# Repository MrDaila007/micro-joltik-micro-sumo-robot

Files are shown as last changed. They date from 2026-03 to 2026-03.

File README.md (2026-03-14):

# Micro Joltik — Micro Sumo Robot

Micro Joltik is an autonomous micro sumo robot that detects opponents using IR proximity sensors and pushes them out of the arena. It features edge detection to stay within the ring boundary and RC5 remote control for start/stop.

## Hardware

- **MCU:** RP2040-zero
- **Motor driver:** TB6612FNG H-bridge driver
- **Motors:** 2× micro gear motors (tank drive)
- **Opponent detection:** 3× Pololu 38kHz IR proximity sensors (front left, center, right)
- **Edge detection:** 1× analog IR line sensor
- **Feedback:** 1× NeoPixel RGB LED
- **Control:** RC5 IR remote receiver
- **Chassis:** Plastic base with SolidWorks-designed 3D-printed parts

## Repository Structure

```
FIRMWARE/
  MicroJoltik_test_Firmware/   # Original test firmware
  MicroJoltik_stable/          # Stable firmware with bug fixes
CAD/                           # SolidWorks mechanical design files
doc/                           # Documentation (changelog, pinout)
```

## Building & Flashing

**Requirements:**
- Arduino IDE (or PlatformIO / VS Code with Arduino extension)
- Libraries: `Adafruit_NeoPixel`, `RC5` (install via Library Manager)

**Steps:**
1. Open `FIRMWARE/MicroJoltik_stable/MicroJoltik_stable.ino` in Arduino IDE
2. Select board: RP2040-Zero
3. Verify (Ctrl+R) to compile
4. Upload (Ctrl+U) to flash

## Configuration

Key `#define` options at the top of the firmware:

| Define | Description |
|---|---|
| `Back_Start` | Enable reverse-and-180° startup routine |
| `ENABLE_LINE_SEN` | Enable edge detection sensor |
| `SWAP_MOTORS` | Swap left/right motor wiring |
| `DEBUG_ENABLE` | Enable serial debug output (9600 baud) |

Speed constants (`MAX_SPEED`, `ATTACK_SPEED`, `SEARCH_SPEED_1/2`, etc.) can be tuned at the top of the file.

## Robot Behavior

1. **Startup** — Waits for RC5 remote start command (LED shows magenta). In debug mode, prints sensor states to serial for calibration.
2. **Start routine** — Backs up, turns a random direction 180°, charges forward, then scans for opponent.
3. **Search** — Spins in a circular pattern looking for opponent with IR sensors.
4. **Attack** — Charges at detected opponent. All three sensors = MAX_SPEED. Single sensor = turn toward opponent.
5. **Edge backoff** — Reverses and U-turns when the line sensor detects the arena boundary.
6. **Stop** — RC5 remote stop command halts all motors (LED shows red).

## License

Apache License 2.0

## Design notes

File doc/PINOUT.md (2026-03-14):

# Micro Joltik Pinout

## Motor Driver (H-Bridge)

| Pin | Function | Description |
|-----|---|---|
| 1 | PWMB | Left motor PWM speed |
| 2 | BIN_1 | Left motor direction |
| 3 | BIN_2 | Left motor direction |
| 4 | STBY | Standby (HIGH=active)|
| 5 | AIN_2 | Right motor direction|
| 6 | AIN_1 | Right motor direction|
| 7 | PWMA | Right motor PWM speed|

## Sensors

| Pin | Function | Description |
|-----|---|---|
| A0  | EDGE_M | Analog IR edge/line sensor |
| 10  | OPPONENT_FL | Front-left IR proximity (38kHz) |
| 11  | OPPONENT_FR | Front-right IR proximity (38kHz)|
| 12  | OPPONENT_FC | Front-center IR proximity (38kHz)|

## Peripherals

| Pin | Function | Description |
|-----|---|---|
| 13  | SenGND  | Sensor ground control |
| 14  | IRVCC | IR sensor power control  |
| 15  | IR_PIN  | RC5 IR remote receiver |
| 16  | PIN | NeoPixel RGB LED (1 pixel)|

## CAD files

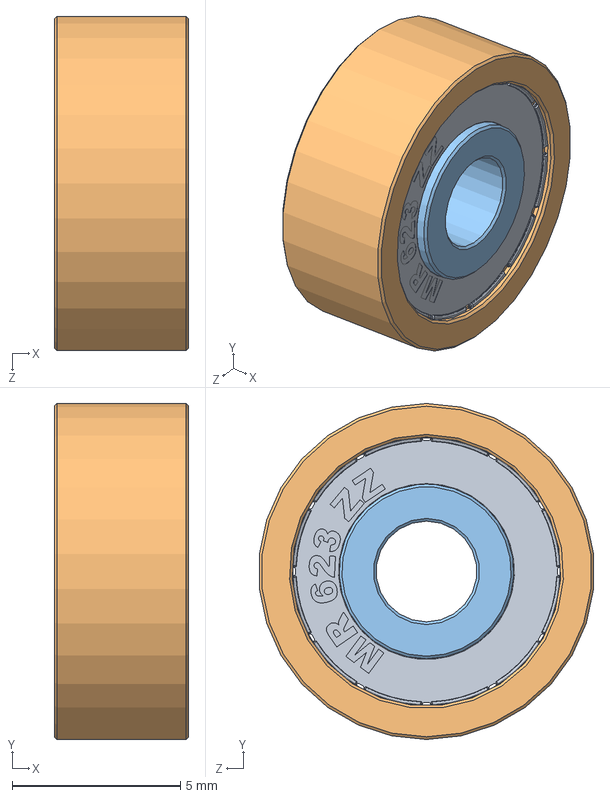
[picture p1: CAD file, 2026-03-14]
CAD/bearing mr623zz/-MR623ZZ-assem.SLDASM
4.00 x 10.0 x 9.95 mm
mr623zz-cen x 2
mr623zz-ext
mr623zz-int

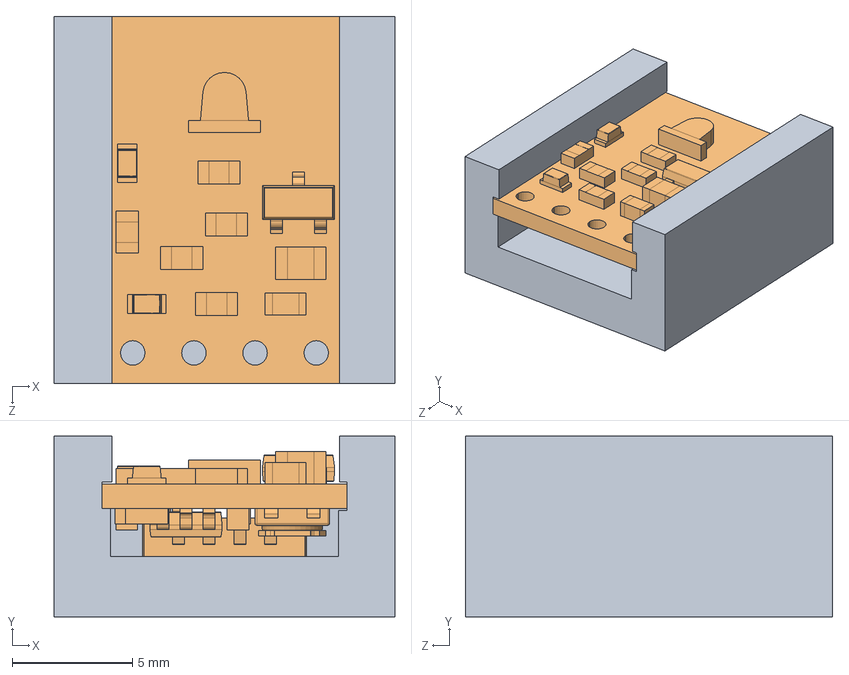
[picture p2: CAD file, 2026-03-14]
CAD/Pololu sensor wihh case.SLDASM
14.2 x 7.50 x 15.2 mm
3 sensores basel
pololu-38-khz-ir-proximity-sensor

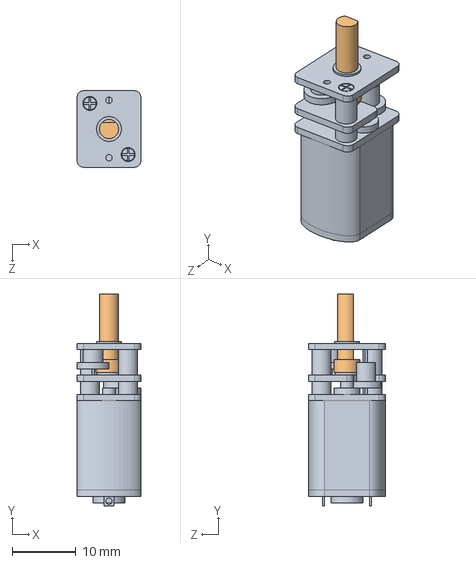
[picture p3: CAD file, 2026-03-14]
CAD/Micro_gear_motor.SLDASM
10.0 x 33.2 x 12.0 mm
Motor
Brazo

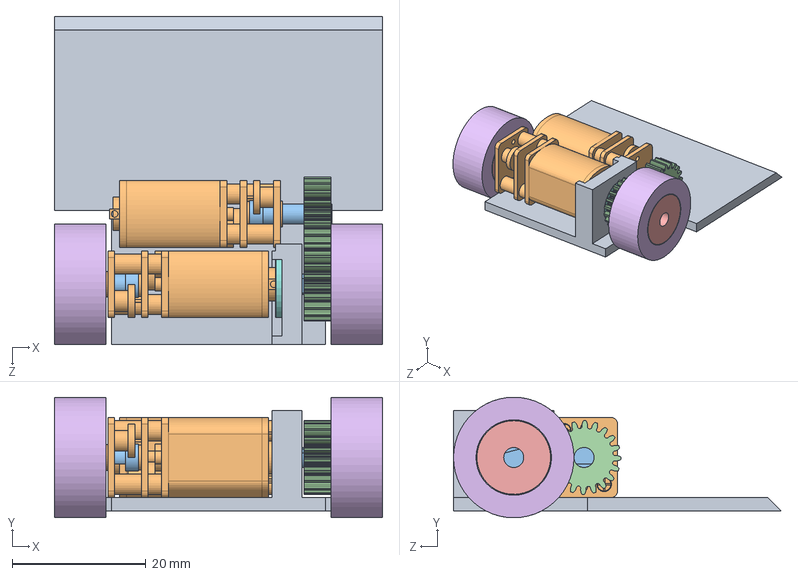
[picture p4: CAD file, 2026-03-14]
CAD/Сборка Micro_Joltik.SLDASM
49.0 x 18.0 x 49.0 mm
Steal_base
Motor x 2
Brazo x 3
Micro Gear x 2
Wheel x 2
Tire_micro x 2
mr623zz-cen x 2
mr623zz-ext
mr623zz-int

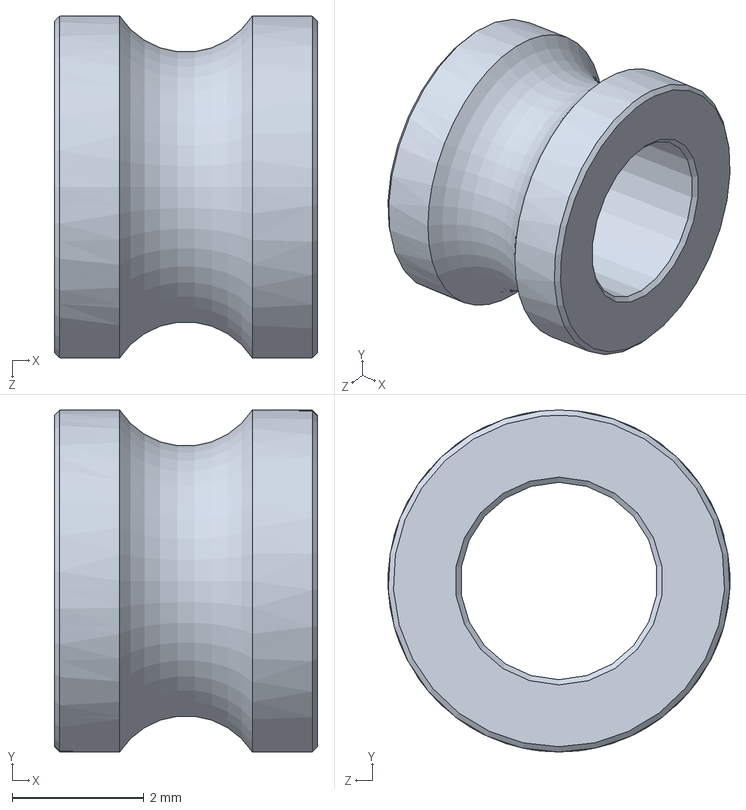
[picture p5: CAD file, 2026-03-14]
CAD/bearing mr623zz/mr623zz-int.SLDPRT
4.00 x 5.20 x 5.20 mm

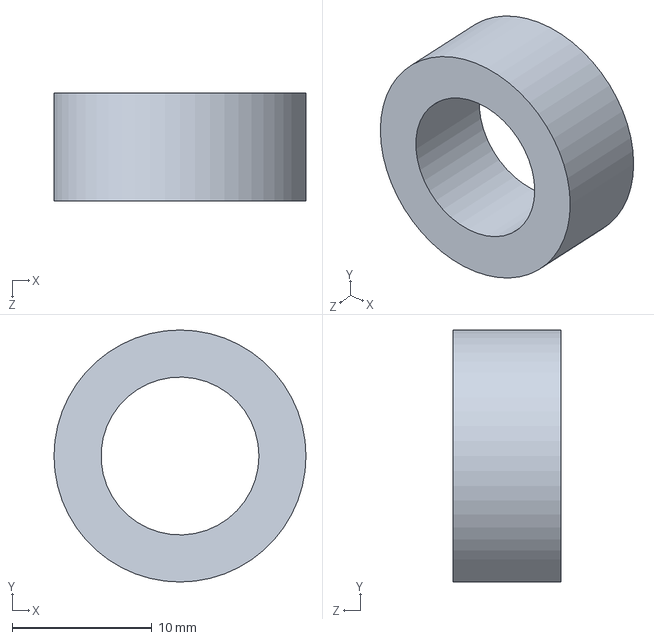
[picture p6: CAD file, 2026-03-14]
CAD/Tire_micro.SLDPRT
18.0 x 18.0 x 7.70 mm

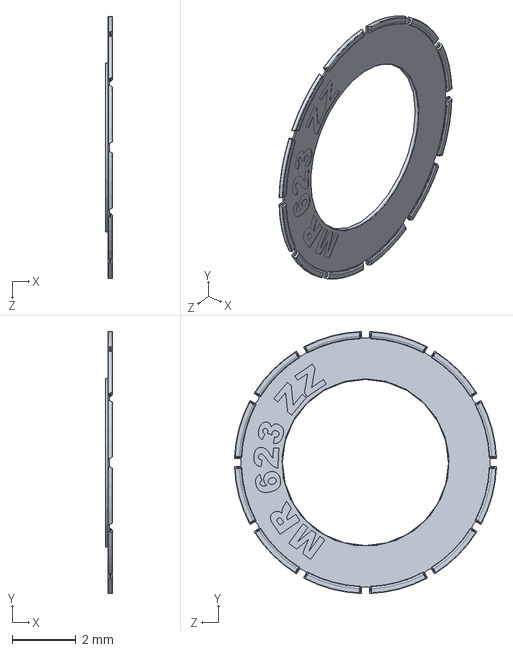
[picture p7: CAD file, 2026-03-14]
CAD/bearing mr623zz/mr623zz-cen.SLDPRT
0.229 x 8.20 x 8.20 mm

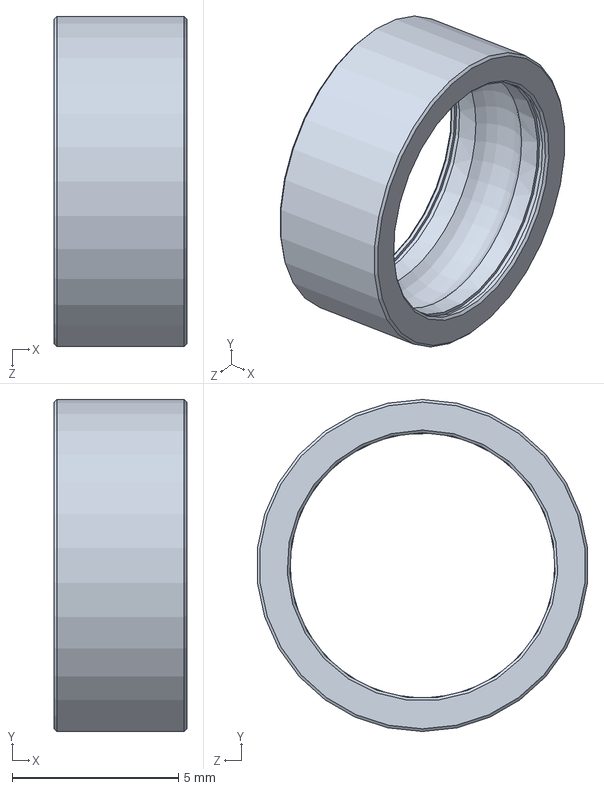
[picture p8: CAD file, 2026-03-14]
CAD/bearing mr623zz/mr623zz-ext.SLDPRT
4.00 x 10.0 x 9.95 mm

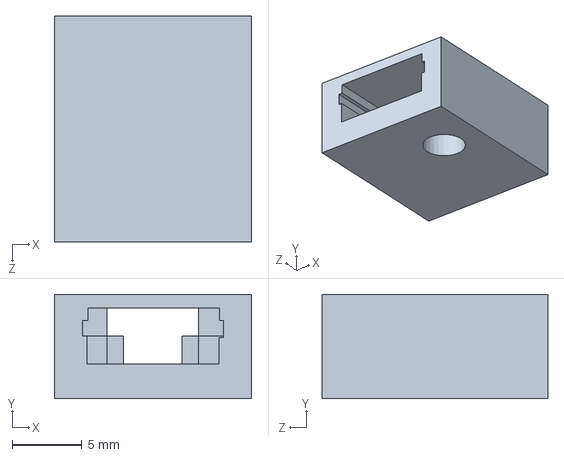
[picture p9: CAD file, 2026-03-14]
CAD/3 sensores basel.SLDPRT
14.2 x 7.50 x 16.2 mm

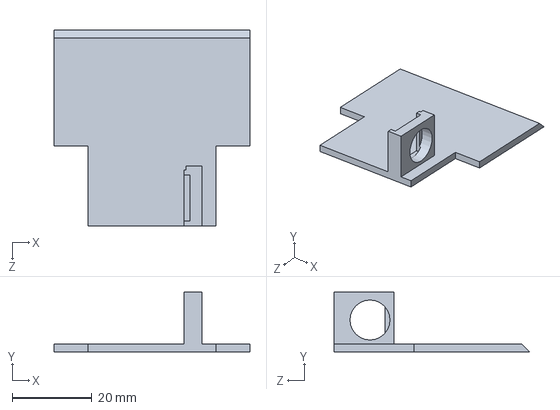
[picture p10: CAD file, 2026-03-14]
CAD/Steal_base.SLDPRT
49.0 x 15.0 x 49.0 mm

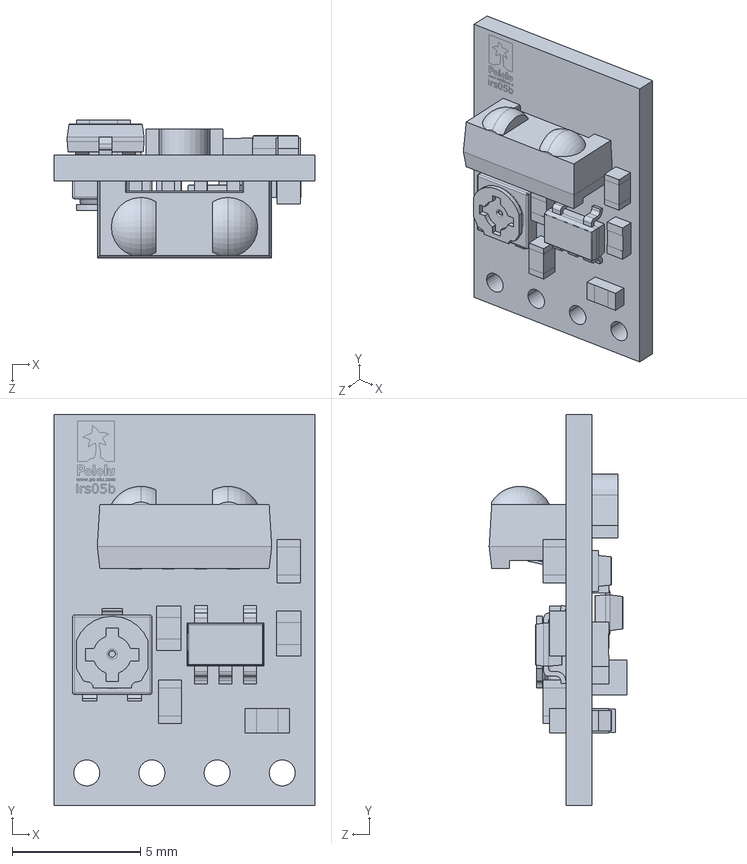
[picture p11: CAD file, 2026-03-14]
CAD/pololu-38-khz-ir-proximity-sensor.SLDPRT
10.2 x 15.2 x 5.37 mm

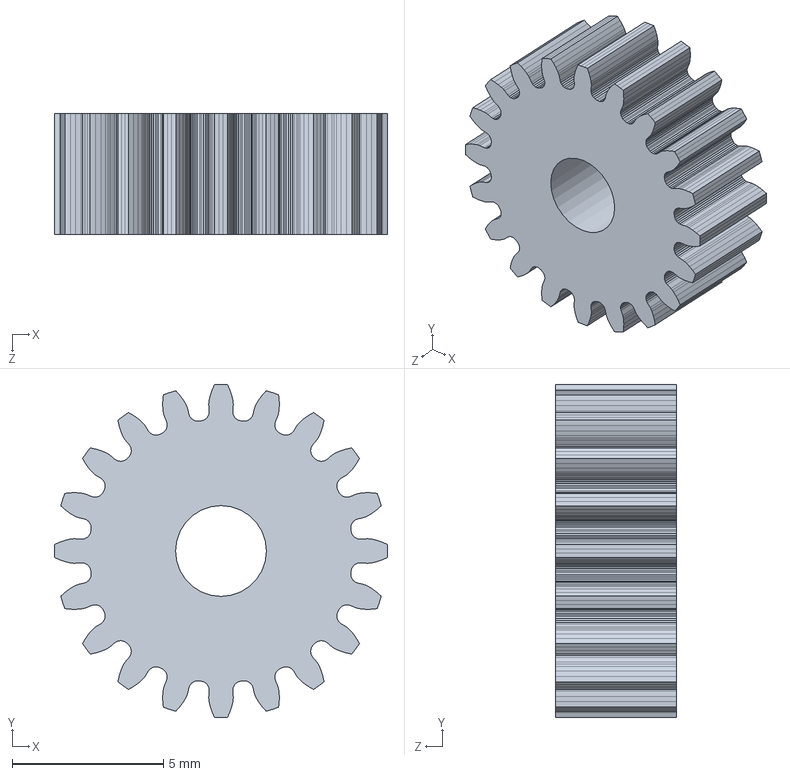
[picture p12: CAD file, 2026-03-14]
CAD/Micro Gear.SLDPRT
11.0 x 11.0 x 4.00 mm

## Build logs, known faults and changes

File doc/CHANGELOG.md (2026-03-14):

# Changelog

## Stable v1.0 (from test firmware)

### Bug Fixes
- **`startRoutine()` line 110:** `if(searchDir = RIGHT)` used assignment `=` instead of comparison `==`, causing the robot to always turn right at startup regardless of the random direction chosen earlier.
- **`attack()` lines 248, 258:** `searchDir == LEFT` and `searchDir == RIGHT` used comparison `==` instead of assignment `=`, so `searchDir` was never updated during attack. The robot would always search in its initial direction after losing an opponent.
- **`attack()` line 237:** The all-three-sensors branch (`OPPONENT_FC && FR && FL`) was unreachable because the single `OPPONENT_FC` check came first. Reordered so all-three-sensors triggers MAX_SPEED before the single-center check.
- **`loop()` bracket scoping:** Fixed the `#ifdef ENABLE_LINE_SEN` conditional bracket structure so the `else` block and its closing brace are properly paired.
- **`EEPROM.begin()` (line 310):** Removed stray space in `EEPROM. begin(512)`.
- **Variable shadowing in `checkIRReceive()`:** Renamed local `int address` to `int eepromAddr` to avoid shadowing the function parameter `unsigned char address`.

### Typo Fixes
- `ATACK_SPEED` → `ATTACK_SPEED`
- `SVAP_MOTORS` → `SWAP_MOTORS`
- `chekIReceive()` → `checkIRReceive()`
- Debug log `"Search_Right"` printed for LEFT direction → fixed to `"Search_Left"`

### Removed
- Commented-out dead attack code (lines 266-298) removed for clarity.

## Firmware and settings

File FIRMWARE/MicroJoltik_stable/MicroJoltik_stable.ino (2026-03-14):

// ============================================================================
//  Micro Joltik — Micro Sumo Robot Firmware (Stable)
//  MCU: RP2040-Zero
//  Wiring connections and pin definitions below.
// ============================================================================

// --- NeoPixel RGB LED ---
#include <Adafruit_NeoPixel.h>
#include <EEPROM.h>
#define PIN 16       // GPIO pin connected to the NeoPixel data line
#define NUMPIXELS 1  // Single RGB LED on the board
Adafruit_NeoPixel pixels(NUMPIXELS, PIN, NEO_GRB + NEO_KHZ800);

// --- RC5 IR Remote Receiver ---
#include <RC5.h>
int IR_PIN = 15;        // GPIO pin for the IR receiver module
unsigned long t0;
RC5 rc5(IR_PIN);
unsigned char dohio;     // Stores the current dohyo (arena) channel from EEPROM

// --- Sensor Pin Definitions ---
// IR sensors read LOW when an object is detected, HIGH when clear.
#define EDGE_M A0       // Analog edge/line sensor (detects white arena boundary)
#define OPPONENT_FR 11  // Front-right IR proximity sensor (38kHz Pololu)
#define OPPONENT_FC 12  // Front-center IR proximity sensor (38kHz Pololu)
#define OPPONENT_FL 10  // Front-left IR proximity sensor (38kHz Pololu)

// --- Sensor Power Pins ---
#define SenGND 13       // Sensor ground control pin (active LOW)
#define IRVCC 14        // IR sensor power control pin (active HIGH)

// --- Behavior Configuration ---
#define Back_Start       // Enable reverse-and-180° startup maneuver
#define ENABLE_LINE_SEN  // Enable edge detection (disable to ignore arena boundary)

//#define DEBUG_ENABLE   // Uncomment to enable serial debug output at 9600 baud

// --- Global State ---
bool result = false;     // Tracks IR remote start/stop state (true = running)
int sensorValue = 0;     // Last raw ADC reading from the edge sensor

// ============================================================================
//  Speed Constants (PWM values 0-255)
//  Tune these to match your motor/gear/wheel combination.
// ============================================================================
#define MAX_SPEED 255           // Absolute maximum motor output
#define STRAIGHT_SPEED 150      // Default forward driving speed
#define SEARCH_SPEED_1 100      // Inner wheel speed during search rotation
#define SEARCH_SPEED_2 100      // Outer wheel speed during search rotation
#define ROTATE_TANK_SPEED 150   // Both-wheels pivot turn speed
#define ROTATE_SPEED 150        // Single-direction rotation speed
#define BRAKEOUT_SPEED 150      // Reverse speed when escaping arena edge
#define ATTACK_SPEED 200        // Charge speed when opponent detected

// ============================================================================
//  Motor Driver Pin Definitions (H-Bridge: TB6612FNG or similar)
//  Each motor uses: 1 PWM pin (speed) + 2 direction pins (IN1/IN2)
// ============================================================================
int difference = 0;
uint32_t myTimer1;
uint8_t attackZone = 0;  // Attack zone tracking (0-12)

// Right motor (Motor A)
int PWMA = 7;    // PWM speed control for right motor
int AIN_2 = 5;   // Right motor direction pin 2
int AIN_1 = 6;   // Right motor direction pin 1

int stdby = 4;   // H-bridge standby pin (HIGH = motors enabled)

// Left motor (Motor B)
int BIN_1 = 2;   // Left motor direction pin 1
int BIN_2 = 3;   // Left motor direction pin 2
int PWMB = 1;    // PWM speed control for left motor

//#define SWAP_MOTORS  // Uncomment if left/right motors are wired in reverse

// --- Direction Constants ---
#define LEFT 0
#define RIGHT 1

// Current search/spin direction. Updated during attack to remember
// which side the opponent was last seen, so search resumes that way.
uint8_t searchDir = LEFT;


// ============================================================================
//  Start Routine
//  Called once when the match begins (after RC5 remote start signal).
//  Executes an opening maneuver to find the opponent quickly.
// ============================================================================
void startRoutine() {
  uint8_t Rand_time = random(150, 240);  // Random delay seed (unused currently)

#ifdef Back_Start
  // --- Back-start strategy: reverse, spin 180°, then charge forward ---

  // Step 1: Drive backward briefly to create distance from starting position
  drive(-BRAKEOUT_SPEED + 5, -BRAKEOUT_SPEED);
  delay(50);

  // Step 2: Pick a random direction and spin 180° to face the arena
  bool rand_DIR = random(0, 2);  // 50/50 chance: 0 = LEFT, 1 = RIGHT
  if (rand_DIR)
  {
    searchDir = RIGHT;
    drive(ROTATE_TANK_SPEED, -ROTATE_TANK_SPEED);  // Pivot right (tank turn)
    delay(210);
  }
  else
  {
    searchDir = LEFT;
    drive(-ROTATE_TANK_SPEED, ROTATE_TANK_SPEED);  // Pivot left (tank turn)
    delay(210);
  }

  // Step 3: Charge forward toward the center of the arena
  drive(STRAIGHT_SPEED, STRAIGHT_SPEED);
  delay(210);

#else
  // --- Simple start strategy: just charge straight forward ---
  drive(STRAIGHT_SPEED, STRAIGHT_SPEED);
  delay(400);

#endif

  // Step 4: Rotate in the chosen direction to scan for opponent
  if (searchDir == RIGHT)
  {
    drive(ROTATE_TANK_SPEED, -ROTATE_TANK_SPEED);  // Pivot right
    delay(210);
  }
  else
  {
    drive(-ROTATE_TANK_SPEED, ROTATE_TANK_SPEED);  // Pivot left
    delay(210);
  }

  // Step 5: Wait for the front-center sensor to detect an opponent (300ms timeout)
  // LOW = opponent detected, HIGH = no opponent
  uint32_t startTimestamp = millis();
  while (!digitalRead(OPPONENT_FC)) {
    if (millis() - startTimestamp > 300) {
      break;  // Give up scanning, continue to main loop
    }
  }
}


// ============================================================================
//  Back Off
//  Called when the edge sensor detects the white arena boundary.
//  Reverses away from the edge, rotates, and tries to reacquire the opponent.
//  @param dir - direction to rotate after reversing (LEFT or RIGHT)
// ============================================================================
void backoff(uint8_t dir) {

  // Step 1: Reverse away from the arena edge at full breakout speed
  drive(-BRAKEOUT_SPEED, -BRAKEOUT_SPEED);
#ifdef DEBUG_ENABLE
  Serial.println("Reverse");
#endif
  delay(100);

  // Step 2: Brief stop before rotating (helps prevent wheel slip)
  drive(0, 0);
  delay(100);

  // Step 3: Rotate away from the edge in the specified direction
  if (dir == LEFT) {
    drive(-ROTATE_SPEED, ROTATE_SPEED);  // Pivot left
#ifdef DEBUG_ENABLE
    Serial.println("Dir_Left");
#endif
  } else {
    drive(ROTATE_SPEED, -ROTATE_SPEED);  // Pivot right
#ifdef DEBUG_ENABLE
    Serial.println("Dir_Right");
#endif
  }
  delay(100);

  // Step 4: While rotating, check if any sensor picks up the opponent (200ms window)
  uint32_t uTurnTimestamp = millis();
  while (millis() - uTurnTimestamp < 200) {
    if (!digitalRead(OPPONENT_FC) || !digitalRead(OPPONENT_FR) || !digitalRead(OPPONENT_FL)) {
      // Opponent found during U-turn — stop and return to main loop for attack
      drive(0, 0);
      delay(50);
#ifdef DEBUG_ENABLE
      Serial.println("BrakeOut Trig");
#endif
      return;
    }
  }

  // Step 5: No opponent found — drive forward and let the main loop handle searching
  drive(STRAIGHT_SPEED, STRAIGHT_SPEED);
  delay(100);
}


// ============================================================================
//  Search
//  Spins the robot in a circular arc to scan for opponents.
//  Direction is determined by the global searchDir variable, which is
//  updated during attack() when the opponent is last seen on one side.
// ============================================================================
void search() {
  // Differential drive creates a circular search path.
  // One wheel drives forward, the other reverses at search speed.
  if (searchDir == LEFT)
  {
    drive(-SEARCH_SPEED_1, SEARCH_SPEED_2);  // Spin left
#ifdef DEBUG_ENABLE
    Serial.println("Search_Left");
#endif
  }
  else if (searchDir == RIGHT)
  {
    drive(SEARCH_SPEED_2, -SEARCH_SPEED_1);  // Spin right
#ifdef DEBUG_ENABLE
    Serial.println("Search_Right");
#endif
  }
}


// ============================================================================
//  Attack
//  Tracks and charges at the opponent based on which sensors detect it.
//  Priority order (highest first):
//    1. All three sensors → MAX_SPEED (opponent dead center, full send)
//    2. Front center only → ATTACK_SPEED (opponent ahead, charge)
//    3. Front left only   → pivot left to align
//    4. Front right only  → pivot right to align
//  Also updates searchDir so if we lose the opponent, we search toward
//  the side it was last seen.
// ============================================================================
void attack() {
  uint32_t attackTimestamp = millis();

  // All three sensors detect opponent — it's right in front, go full power
  if (!digitalRead(OPPONENT_FC) && !digitalRead(OPPONENT_FR) && !digitalRead(OPPONENT_FL))
  {
    drive(MAX_SPEED, MAX_SPEED);
#ifdef DEBUG_ENABLE
    Serial.println("Attack Front Max speed");
#endif
  }

  // Only front-center detects — opponent is ahead, charge at attack speed
  else if (!digitalRead(OPPONENT_FC))
  {
    drive(ATTACK_SPEED, ATTACK_SPEED);
#ifdef DEBUG_ENABLE
    Serial.println("Attack Front");
#endif
  }

  // Only front-left detects — opponent is to the left, pivot to align
  else if (!digitalRead(OPPONENT_FL)) {
    searchDir = LEFT;   // Remember: opponent was last seen on the left
    drive(0, ROTATE_TANK_SPEED);  // Left wheel stopped, right wheel forward
#ifdef DEBUG_ENABLE
    Serial.println("Attack Front left");
#endif
  }

  // Only front-right detects — opponent is to the right, pivot to align
  else if (!digitalRead(OPPONENT_FR)) {
    searchDir = RIGHT;  // Remember: opponent was last seen on the right
    drive(ROTATE_TANK_SPEED, 0);  // Left wheel forward, right wheel stopped
#ifdef DEBUG_ENABLE
    Serial.println("Attack Front right");
#endif
  }
}


// ============================================================================
//  Setup
//  Runs once after power-on or reset.
//  Initializes hardware, loads settings from EEPROM, and waits for
//  the RC5 remote start command before beginning the match.
// ============================================================================
void setup() {

  // Load the dohyo channel number from EEPROM (persists across power cycles).
  // This value is set via RC5 remote with address=11 and determines which
  // start/stop commands the robot responds to (for multi-robot arenas).
  EEPROM.begin(512);
  unsigned char value;
  int eepromAddr = 100;  // EEPROM storage address for the dohyo channel
  EEPROM.get(eepromAddr, value);
  dohio = value;

#ifdef DEBUG_ENABLE
  Serial.begin(9600);
  Serial.println("Robot has been started!");
  Serial.print("Dohio = ");
  Serial.println(dohio);
#endif

  // --- Configure motor driver pins as outputs ---
  pinMode(BIN_1, OUTPUT);
  pinMode(BIN_2, OUTPUT);
  pinMode(AIN_1, OUTPUT);
  pinMode(AIN_2, OUTPUT);

  // --- Configure power and control pins ---
  pinMode(stdby, OUTPUT);
  pinMode(SenGND, OUTPUT);
  pinMode(IRVCC, OUTPUT);

  // --- Configure sensor pins as inputs ---
  pinMode(OPPONENT_FL, INPUT);
  pinMode(OPPONENT_FC, INPUT);
  pinMode(OPPONENT_FR, INPUT);

  // --- Activate hardware ---
  digitalWrite(stdby, 1);   // Enable H-bridge (exit standby mode)
  digitalWrite(SenGND, 0);  // Set sensor ground LOW
  digitalWrite(IRVCC, 1);   // Power on IR proximity sensors

  // --- Initialize NeoPixel LED ---
  pixels.begin();
  pixels.clear();
  Blink(255, 255, 0);  // Yellow double-blink to indicate boot complete

  // Ensure motors are stopped
  drive(0, 0);

  // Show magenta LED while waiting for start command
  pixels.setPixelColor(0, pixels.Color(125, 0, 125));
  pixels.show();

  // --- Wait for RC5 remote start command ---
  // Robot sits idle displaying magenta LED. In debug mode, sensor states
  // are printed to serial for calibration and troubleshooting.
  while (checkIRReceive()) {
#ifdef DEBUG_ENABLE
    bool FRONT_L_State = digitalRead(OPPONENT_FL);
    bool FRONT_State = digitalRead(OPPONENT_FC);
    bool FRONT_R_State = digitalRead(OPPONENT_FR);
    bool LINE_State = LineSens();

    // Output format: FL FC FR EDGE ADC_VALUE
    Serial.print(FRONT_L_State);
    Serial.print(" ");
    Serial.print(FRONT_State);
    Serial.print(" ");
    Serial.print(FRONT_R_State);
    Serial.print(" ");
    Serial.print(!LINE_State);
    Serial.println(" ");
    Serial.print(sensorValue);
    Serial.println(" ");
#endif
  }

  // Wait for the start button release (debounce)
  while (!checkIRReceive())
  {
    pixels.setPixelColor(0, pixels.Color(125, 0, 125));
    pixels.show();
#ifdef DEBUG_ENABLE
    bool FRONT_L_State = digitalRead(OPPONENT_FL);
    bool FRONT_State = digitalRead(OPPONENT_FC);
    bool FRONT_R_State = digitalRead(OPPONENT_FR);
    bool LINE_State = LineSens();

    Serial.print(FRONT_L_State);
    Serial.print(" ");
    Serial.print(FRONT_State);
    Serial.print(" ");
    Serial.print(FRONT_R_State);
    Serial.print(" ");
    Serial.print(!LINE_State);
    Serial.println(" ");
    Serial.print(sensorValue);
    Serial.println(" ");
#endif
  }

  // Match begins — run the opening maneuver
  startRoutine();
}

// ============================================================================
//  Main Loop
//  Runs continuously after setup. Implements the core behavior state machine:
//    1. Check edge sensor → backoff if arena boundary detected
//    2. Check opponent sensors → attack if detected, search if not
//    3. Check RC5 remote → stop if stop command received
// ============================================================================
void loop() {

#ifdef ENABLE_LINE_SEN
  // --- Edge Detection ---
  // LineSens() returns true (1) if on the arena surface, false (0) if edge detected.
  // When edge is detected, reverse and toggle search direction.
  if (!LineSens())
  {
    backoff(RIGHT);
    searchDir ^= 1;  // Flip search direction (LEFT <-> RIGHT) using XOR
  }
  else
  {
#endif

  // --- Opponent Detection ---
  // All IR sensors read HIGH when no object is present.
  // If all three sensors are clear, keep searching.
  if (digitalRead(OPPONENT_FC) && digitalRead(OPPONENT_FL) && digitalRead(OPPONENT_FR)) {
#ifdef DEBUG_ENABLE
    Serial.println("GO SEARCH void");
#endif
    search();
  }
  // At least one sensor detects the opponent — switch to attack mode.
  else
  {
#ifdef DEBUG_ENABLE
    Serial.println("GO to Attack void");
#endif
    attack();
  }

#ifdef ENABLE_LINE_SEN
  }  // Close the else block from edge detection
#endif

  // --- Remote Stop Check ---
  // If the RC5 remote sends a stop command, halt the robot permanently.
  // The red LED indicates stopped state. Requires hardware reset to restart.
  if (checkIRReceive() == 0) {
    while (true) {
      pixels.setPixelColor(0, pixels.Color(150, 0, 0));
      pixels.show();
      drive(0, 0);
    }
  }
}


// ============================================================================
//  Drive
//  Controls both motors simultaneously. Positive values = forward, negative = reverse.
//  Handles direction pin logic for the H-bridge and applies PWM speed.
//  @param leftS  - left motor speed (-255 to 255)
//  @param rightS - right motor speed (-255 to 255)
// ============================================================================
void drive(int leftS, int rightS) {

#ifdef SWAP_MOTORS
  // If motors are wired in reverse, swap the values
  int left = rightS;
  int right = leftS;
#else
  int left = leftS;
  int right = rightS;
#endif

  // Clamp speed values to valid PWM range
  left = constrain(left, -255, 255);
  right = constrain(right, -255, 255);

  // Set left motor (B) direction via H-bridge pins
  if (left >= 0) {
    digitalWrite(BIN_1, LOW);
    digitalWrite(BIN_2, HIGH);   // Forward
  } else {
    digitalWrite(BIN_1, HIGH);
    digitalWrite(BIN_2, LOW);    // Reverse
  }

  // Set right motor (A) direction via H-bridge pins
  if (right >= 0) {
    digitalWrite(AIN_1, LOW);
    digitalWrite(AIN_2, HIGH);   // Forward
  } else {
    digitalWrite(AIN_1, HIGH);
    digitalWrite(AIN_2, LOW);    // Reverse
  }

  // Apply speed via PWM (absolute value since direction is set above)
  analogWrite(PWMA, abs(right));
  analogWrite(PWMB, abs(left));
}


// ============================================================================
//  Blink
//  Flashes the NeoPixel LED twice in the specified color.
//  Used for visual status feedback (boot, error, mode change).
//  @param R, G, B - color values (0-255)
// ============================================================================
void Blink(int R, int G, int B) {
  pixels.clear();
  pixels.setPixelColor(0, pixels.Color(R, G, B));
  pixels.show();
  delay(500);
  pixels.setPixelColor(0, pixels.Color(0, 0, 0));
  pixels.show();
  delay(500);
  pixels.setPixelColor(0, pixels.Color(R, G, B));
  pixels.show();
  delay(500);
  pixels.setPixelColor(0, pixels.Color(0, 0, 0));
  pixels.show();
}

// ============================================================================
//  checkIRReceive
//  Reads RC5 IR remote commands and handles two functions:
//
//  1. Channel setting (address=11): Stores the dohyo channel in EEPROM.
//     This lets multiple robots share an arena with different remotes.
//     Blue blink confirms the channel was set.
//
//  2. Start/Stop (address=7):
//     - command == dohio     → STOP  (red LED, result = false)
//     - command == dohio + 1 → START (green LED, result = true)
//
//  @return true if robot should be running, false if stopped
// ============================================================================
bool checkIRReceive() {
  unsigned char toggle;
  unsigned char address;
  unsigned char command;

  if (rc5.read(&toggle, &address, &command)) {

    // --- Channel configuration command (address 11) ---
    if (address == 11) {
      if (dohio != command)
      {
        // Save new channel to EEPROM
        int eepromAddr = 100;
        EEPROM.put(eepromAddr, command);
        EEPROM.commit();
        dohio = command;

        // Verify the write was successful
        unsigned char value;
        EEPROM.get(eepromAddr, value);
        if (value != dohio)
        {
          Blink(255, 0, 0);  // Red blink = EEPROM write error
#ifdef DEBUG_ENABLE
          Serial.println("EEPROM write ERR");
#endif
        }
      }
      dohio = command;
      Blink(0, 0, 255);  // Blue blink = channel set confirmation
    }

    // --- Stop command: address 7, command matches current channel ---
    if (address == 7 && command == dohio) {
      result = false;
      pixels.setPixelColor(0, pixels.Color(150, 0, 0));  // Red = stopped
      pixels.show();
    }

    // --- Start command: address 7, command = channel + 1 ---
    if (address == 7 && command == dohio + 1) {
      result = true;
      pixels.setPixelColor(0, pixels.Color(0, 150, 0));  // Green = running
      pixels.show();
    }
  }
  return result;
}


// ============================================================================
//  LineSens
//  Reads the analog edge sensor and returns whether the robot is safely
//  on the arena surface.
//
//  The sensor reads different ADC values based on surface reflectivity:
//    - < 200: Off the edge / white boundary line detected → return 0 (unsafe)
//    - > 500: On the dark arena surface → return 1 (safe)
//    - 200-500: Dead zone — returns previous state (hysteresis)
//
//  @return true (1) if on arena surface, false (0) if edge detected
// ============================================================================
bool LineSens() {
  bool State = 0;
  sensorValue = analogRead(EDGE_M);
  if (sensorValue < 200) {
    State = 0;  // Edge detected (white boundary)
  } else if (sensorValue > 500) {
    State = 1;  // Safe (dark arena surface)
  }
  // Values 200-500 are in the dead zone; State stays 0 (defaults to unsafe)
  return State;
}

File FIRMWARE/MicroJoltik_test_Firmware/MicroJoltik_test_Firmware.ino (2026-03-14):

// Wiring Connections.
#include <Adafruit_NeoPixel.h>
#include <EEPROM.h>
#define PIN 16       // номер порта к которому подключен модуль
#define NUMPIXELS 1  // Popular NeoPixel ring size
Adafruit_NeoPixel pixels(NUMPIXELS, PIN, NEO_GRB + NEO_KHZ800);


#include <RC5.h>
int IR_PIN = 15;
unsigned long t0;
RC5 rc5(IR_PIN);
unsigned char dohio;

#define EDGE_M A0       // Right edge sensor
#define OPPONENT_FR 11  // Front right opponent sensor
#define OPPONENT_FC 12  // Front center opponent sensor
#define OPPONENT_FL 10  // Front left opponent sensor

#define SenGND 13
#define IRVCC 14

#define Back_Start
#define ENABLE_LINE_SEN


//#define DEBUG_ENABLE

bool result = false;
int sensorValue = 0;

////////////////////////////////////
//////////// SPEED ////////////////
//////////////////////////////////
#define MAX_SPEED 255
#define STRAIGHT_SPEED 150
#define SEARCH_SPEED_1 100
#define SEARCH_SPEED_2 100
#define ROTATE_TANK_SPEED 150
#define ROTATE_SPEED 150
#define BRAKEOUT_SPEED 150
#define ATACK_SPEED 200

////////////////////////////////
int difference = 0;
uint32_t myTimer1;
uint8_t attackZone = 0;  //0-12


int PWMA = 7;
int AIN_2 = 5;
int AIN_1 = 6;
int stdby = 4;
int BIN_1 = 2;
int BIN_2 = 3;
int PWMB = 1;

//#define SVAP_MOTORS

// Direction.
#define LEFT 0
#define RIGHT 1

// Global variables.
uint8_t searchDir = LEFT;


// Configure the motor driver.


/*******************************************************************************
   Start Routine
   This function should be called once only when the game start.
 *******************************************************************************/
void startRoutine() {
  // Start delay.
  uint8_t Rand_time = random(150,240);
#ifdef Back_Start

  drive(-BRAKEOUT_SPEED+5, -BRAKEOUT_SPEED); // Go Back.
  delay(50);
  
  bool rand_DIR = random(0,2);
  if(rand_DIR)
  {
    searchDir = RIGHT;
    drive(ROTATE_TANK_SPEED, -ROTATE_TANK_SPEED); // Turn round
    delay(210);
  }
  else
  {
    searchDir = LEFT;
    drive(-ROTATE_TANK_SPEED, ROTATE_TANK_SPEED); // Turn round
    delay(210);
  }

  drive(STRAIGHT_SPEED, STRAIGHT_SPEED);
  delay(210);

#else

  drive(STRAIGHT_SPEED, STRAIGHT_SPEED);
  delay(400);

#endif
  // Go straight.


  // Turn left until opponent is detected.
    if(searchDir = RIGHT)
  {
    searchDir = RIGHT;
    drive(ROTATE_TANK_SPEED, -ROTATE_TANK_SPEED); // Turn round
    delay(210);
  }
  else
  {
    searchDir = LEFT;
    drive(-ROTATE_TANK_SPEED, ROTATE_TANK_SPEED); // Turn round
    delay(210);
  }
  uint32_t startTimestamp = millis();
  while (!digitalRead(OPPONENT_FC)) {
    // Quit if opponent is not found after timeout.
    if (millis() - startTimestamp > 300) {
      break;
    }
  }
}


/*******************************************************************************
   Back Off
   This function should be called when the ring edge is detected.
 *******************************************************************************/
void backoff(uint8_t dir) {
  // Stop the motors.

  // Reverse.
  drive(-BRAKEOUT_SPEED, -BRAKEOUT_SPEED);
#ifdef DEBUG_ENABLE
  Serial.println("Reverse");
#endif

  delay(100);

  // Stop the motors.
  drive(0, 0);

  delay(100);

  // Rotate..
  if (dir == LEFT) {
    drive(-ROTATE_SPEED, ROTATE_SPEED);

#ifdef DEBUG_ENABLE
    Serial.println("Dir_Left");
#endif


  } else {
    drive(ROTATE_SPEED, -ROTATE_SPEED);

#ifdef DEBUG_ENABLE
    Serial.println("Dir_Right");
#endif
  }
  delay(100);

  // Start looking for opponent.
  // Timeout after a short period.
  uint32_t uTurnTimestamp = millis();
  while (millis() - uTurnTimestamp < 200) {
    // Opponent is detected if either one of the opponent sensor is triggered.
    if (!digitalRead(OPPONENT_FC) || !digitalRead(OPPONENT_FR) || !digitalRead(OPPONENT_FL)) {

      // Stop the motors.
      drive(0, 0);
      delay(50);
        #ifdef DEBUG_ENABLE
          Serial.println("BrakeOut Trig");
        #endif

      // Return to the main loop and run the attach program.
      return;
    }
  }

  // If opponent is not found, move forward and continue searching in the main loop..

  drive(STRAIGHT_SPEED, STRAIGHT_SPEED);

  delay(100);
}


/*******************************************************************************
   Search
 *******************************************************************************/
void search() {
  // Move in circular motion.
  if (searchDir == LEFT) 
  {
    drive(-SEARCH_SPEED_1, SEARCH_SPEED_2);
      #ifdef DEBUG_ENABLE
        Serial.println("Search_Right");
      #endif
  } 
  else if (searchDir == RIGHT) 
  {
    drive(SEARCH_SPEED_2, -SEARCH_SPEED_1);
      #ifdef DEBUG_ENABLE
        Serial.println("Search_Right");
      #endif
  }
}


/*******************************************************************************
   Attack
   Track and attack the opponent in full speed.
   Do nothing if opponent is not found.
 *******************************************************************************/
void attack() {
  uint32_t attackTimestamp = millis();

  // Opponent in front center.
  // Go straight in full speed.
  if (!digitalRead(OPPONENT_FC)) 
  {
    drive(ATACK_SPEED, ATACK_SPEED);
    #ifdef DEBUG_ENABLE
      Serial.println("Attack Front");
    #endif
  }

  else if (!digitalRead(OPPONENT_FC) && !digitalRead(OPPONENT_FR) && !digitalRead(OPPONENT_FL)) 
  {
    drive(MAX_SPEED, MAX_SPEED);
      #ifdef DEBUG_ENABLE
        Serial.println("Attack Front Max speed");
      #endif
  }

  // Opponent in front left.
  // Turn left.
  else if (!digitalRead(OPPONENT_FL)) {
    searchDir == LEFT;
    drive(0, ROTATE_TANK_SPEED);
      #ifdef DEBUG_ENABLE
        Serial.println("Attack Front left");
      #endif
  }

  // Opponent in front right.
  // Turn right.
  else if (!digitalRead(OPPONENT_FR)) {
        searchDir == RIGHT;
    drive(ROTATE_TANK_SPEED, 0);
      #ifdef DEBUG_ENABLE
        Serial.println("Attack Front right");
      #endif
  }

 
/*
  // Opponent in left side.
  // Rotate left until opponent is in front.
  else if (!digitalRead(OPPONENT_FL)) {
    searchDir == LEFT;
    drive(-ROTATE_SPEED, ROTATE_SPEED);
#ifdef DEBUG_ENABLE
    Serial.println("Attack LEFT");
#endif
    while (!digitalRead(OPPONENT_FC)) {
      // Quit if opponent is not found after timeout.
      if (millis() - attackTimestamp > 400) {
        break;
      }
    }
  }

  // Opponent in right side.
  // Rotate right until opponent is in front.
  else if (!digitalRead(OPPONENT_FR)) {
    searchDir == RIGHT;
    drive(ROTATE_SPEED, -ROTATE_SPEED);
      #ifdef DEBUG_ENABLE
        Serial.println("Attack RIGHT");
      #endif
    while (!digitalRead(OPPONENT_FC)) {
      // Quit if opponent is not found after timeout.
      if (millis() - attackTimestamp > 400) {
        break;
      }
    }
  }
  */
}
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

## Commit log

2026-03-14 Add CAD files
    [-MR623ZZ-assem.SLDASM, 3 sensores basel.SLDPRT, Micro Gear.SLDPRT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]
2026-03-14 Add stable firmware, docs, README, and gitignore
    - Add stable firmware with bug fixes (==/= operators, attack priority, bracket scoping)
    - Add README with hardware info, build instructions, and behavior description
    - Add doc/ with CHANGELOG and PINOUT reference
    - Add .gitignore for build artifacts, IDE files, SolidWorks temp files
    [MicroJoltik_stable.ino]
